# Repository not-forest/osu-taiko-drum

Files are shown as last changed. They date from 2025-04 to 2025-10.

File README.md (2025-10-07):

# 🥁 Osu! Taiko Drum Controller

A cross-platform, DIY **Taiko drum controller** designed for playing **[osu!taiko](https://osu.ppy.sh/home)** on PC. This controller functions as a fully configurable keypad that detects vibration-based hits and maps them to keypress events, serving as a general-purpose input device.

The project includes:

- Hardware schematics and PCB layout  
- Firmware written in Rust using RTIC framework
- GUI interface for configuring the drum from the host side (TODO!)
- Jupyter notebook for simulating piezoelectric sensor signals and modeling post-processing, which is then rewritten within the firmware in no_std environment
- A command-line utility for configuring the drum from the host side.  
- 3D-printable components for building the physical enclosure

---
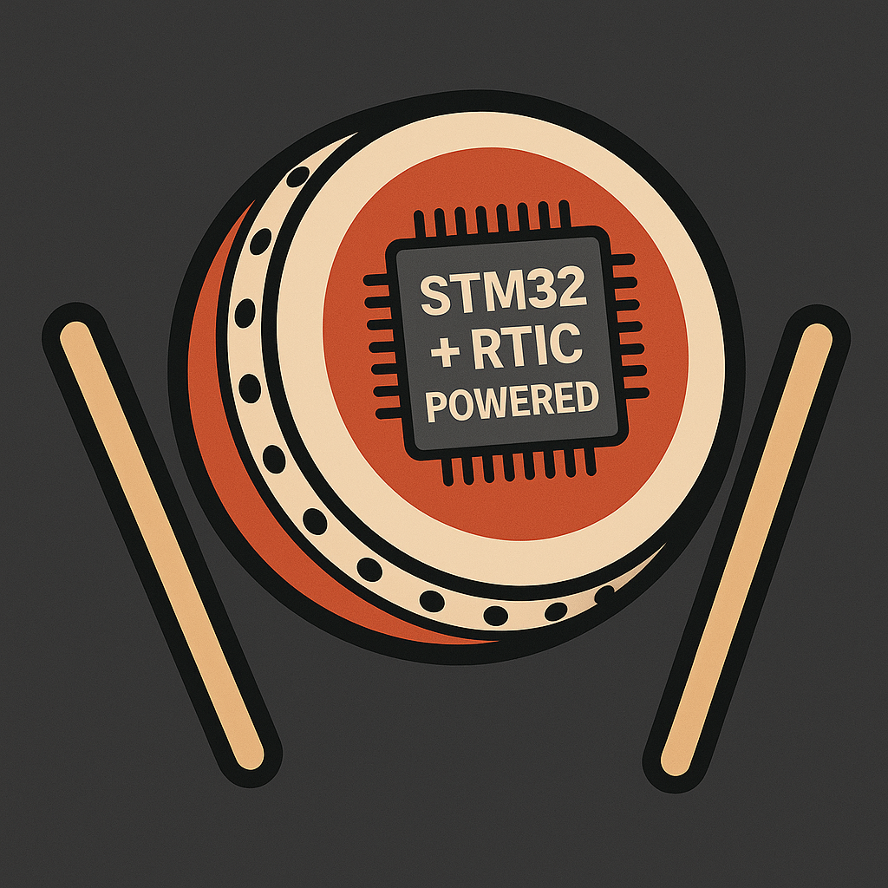
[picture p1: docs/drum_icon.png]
Taiko Drum Controller Icon

---

## Visual Overview

- **Assembled Physical Drum Controller**  
  Assembled Physical Representation

- **Electronic Schematic**  
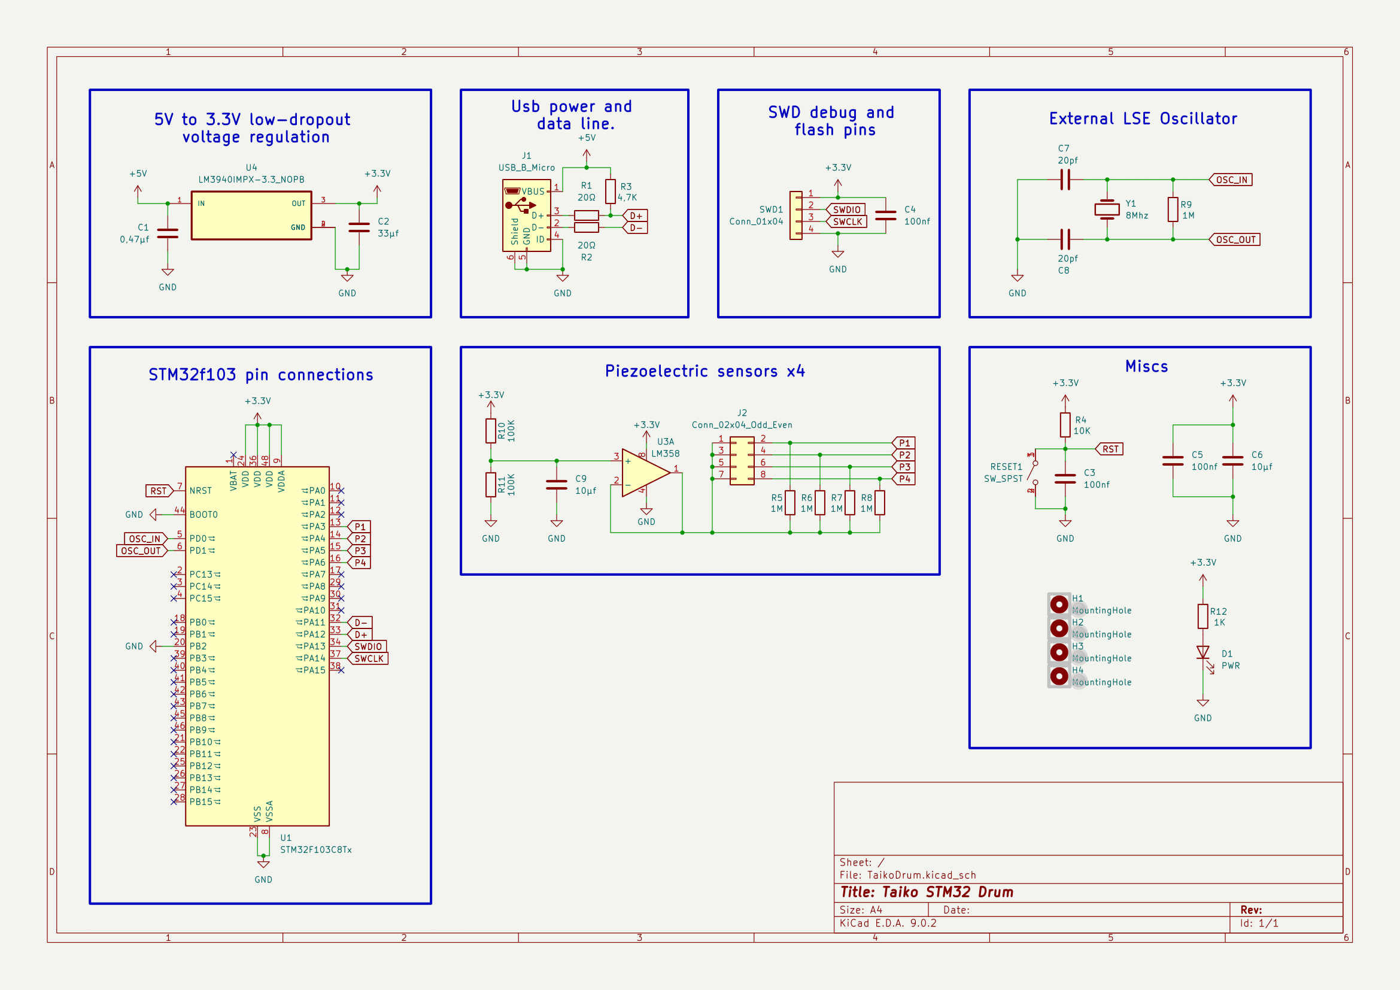
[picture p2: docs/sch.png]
Schematic
  

- **PCB Layout**  
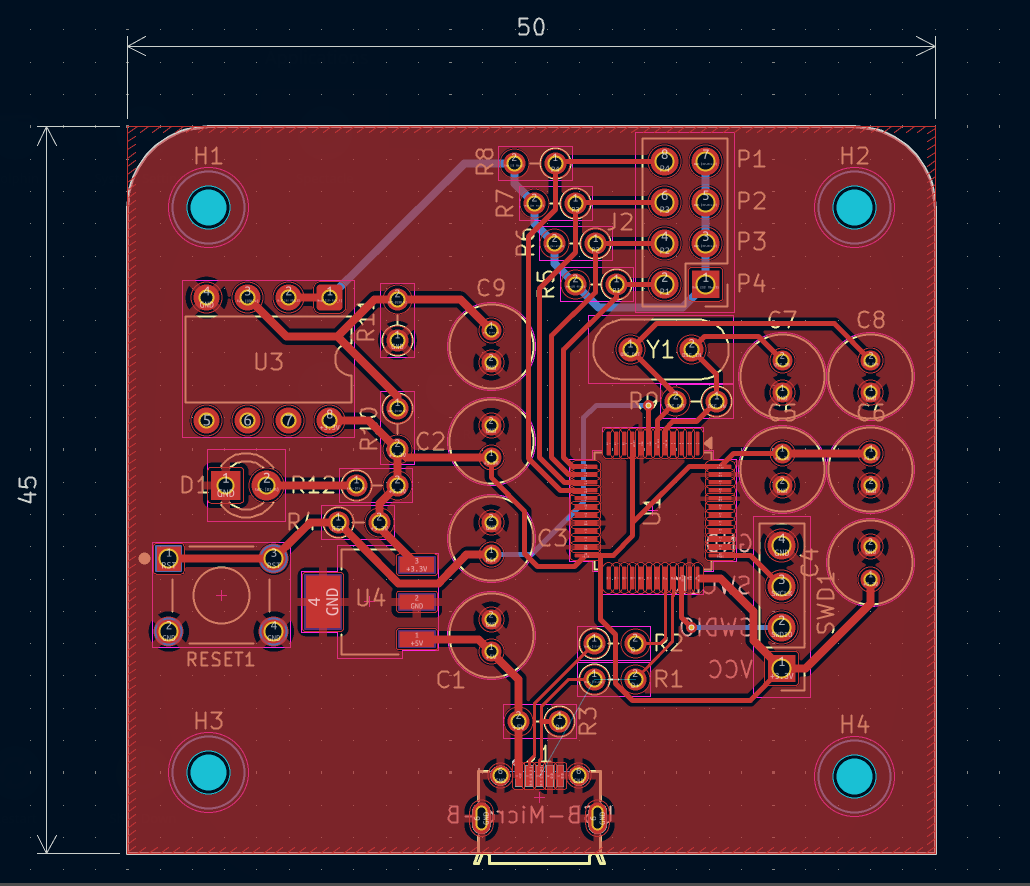
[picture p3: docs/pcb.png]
PCB Layout
  

---

### Project Overview

---

## Firmware

The firmware is written in Rust using the [RTIC framework](https://rtic.rs/), simulating a general-purpose HID device to ensure compatibility across all major operating systems. It simultaneously exposes a serial interface for configuration and control via utility software.

Each of the four piezoelectric sensors is sampled independently using dedicated ADC channels. The firmware captures both "Don" and "Kat" hits in pairs with minimal latency. Captured samples are fed into a queue and processed by a parser task that performs post-processing to detect real and spurious hits. Inner constants like `sensitivity` and `sharpness` are configurable from the utility software. Valid hits are mapped into keypresses and transmitted as USB HID reports.

All configuration data is stored in the last page of the flash memory and can be updated at runtime using the configuration utility.

---

## Hardware

The custom PCB is designed in KiCad and features core components typically found on “Blue Pill” development boards, including SWD debug headers and an onboard reset button. The controller is powered directly via USB, which also serves as the communication link for HID reports to the host system.

---

## Configuration Utility (TODO! swap to GUI utility)

A lightweight command-line utility written in Tcl is provided for runtime configuration. It allows to:

- Remap keypresses for each sensor. Can be changed to any proper keyboard key.
- Adjust hit detection `sensitivity` and `sharpness` to fine tune inner hit detection algorithm
- Send control commands, such as firmware reboot.
- Firmware update support (TODO!)

---

## 3D Printed Parts

All necessary 3D-printable components are located in the `3d/` directory. This includes:

- Raw Blender model files
- Cura-ready imported `.3mf` files

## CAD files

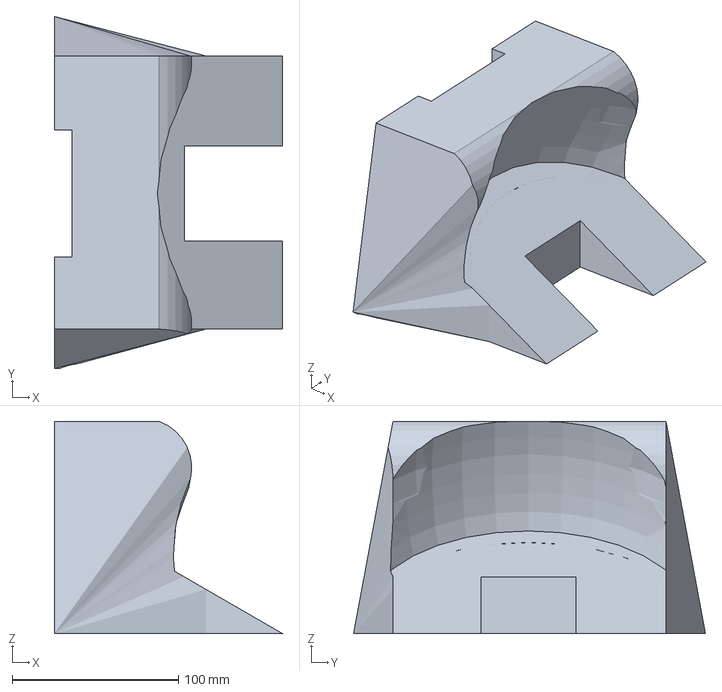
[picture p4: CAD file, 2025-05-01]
3d/SS_TaikoDrumStandFront.3mf
137.4 x 211.9 x 127.8 mm

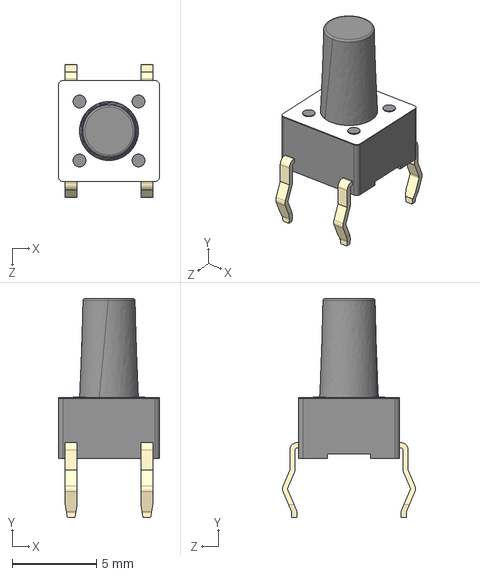
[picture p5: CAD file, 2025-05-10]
pcb/syms/FSM8JH/FSM8JH.step
5.99 x 13.0 x 7.90 mm

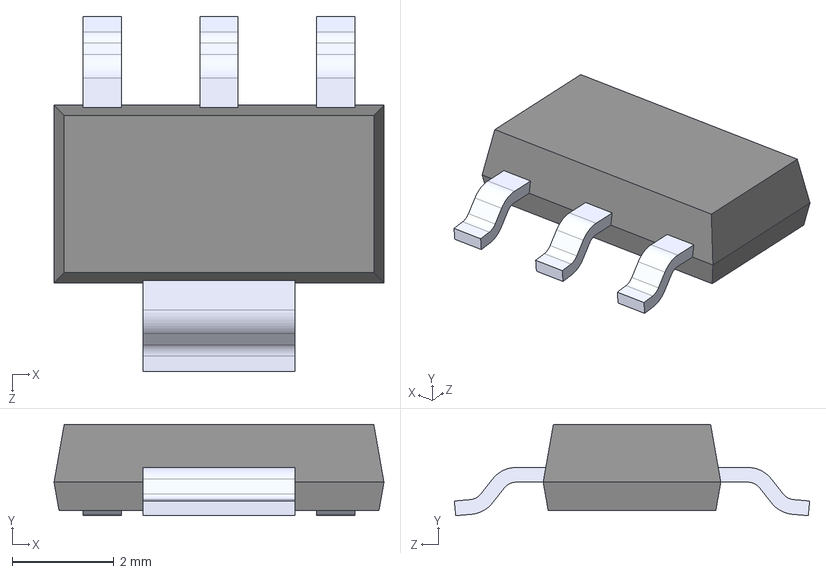
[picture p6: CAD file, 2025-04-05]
pcb/syms/LM3940IMPX-3.3_NOPB/LM3940IMPX-3.3_NOPB.step
6.50 x 1.80 x 7.00 mm

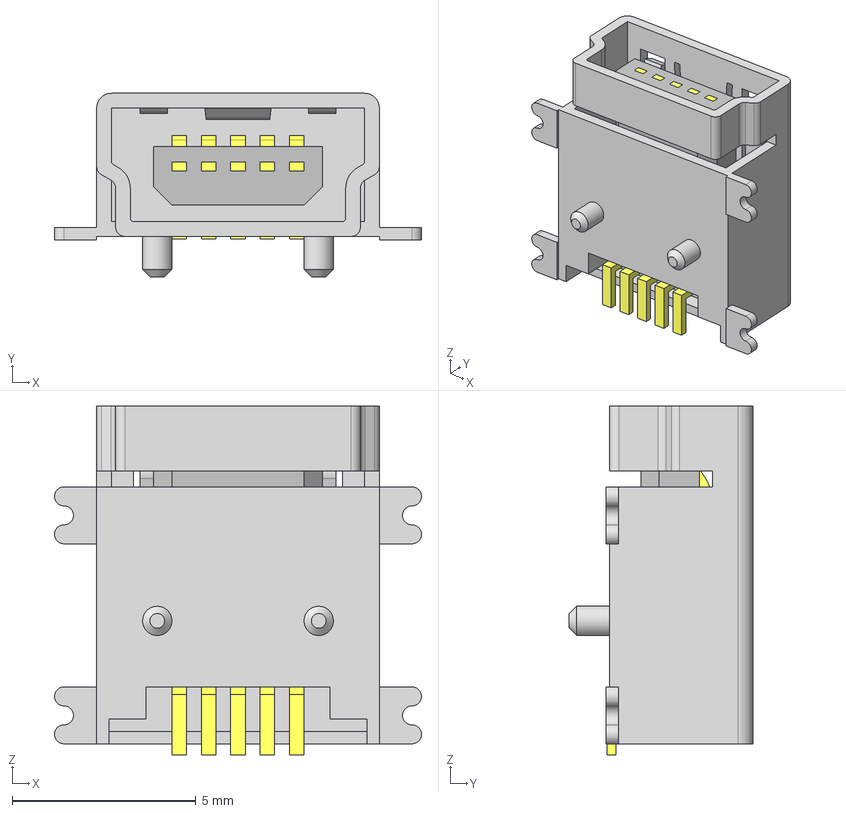
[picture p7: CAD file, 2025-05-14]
pcb/syms/MUSB-05-S-B-SM-A.stp
10.00 x 5.00 x 9.50 mm
MUSBB
MUSB-Body
MUSB-Pin

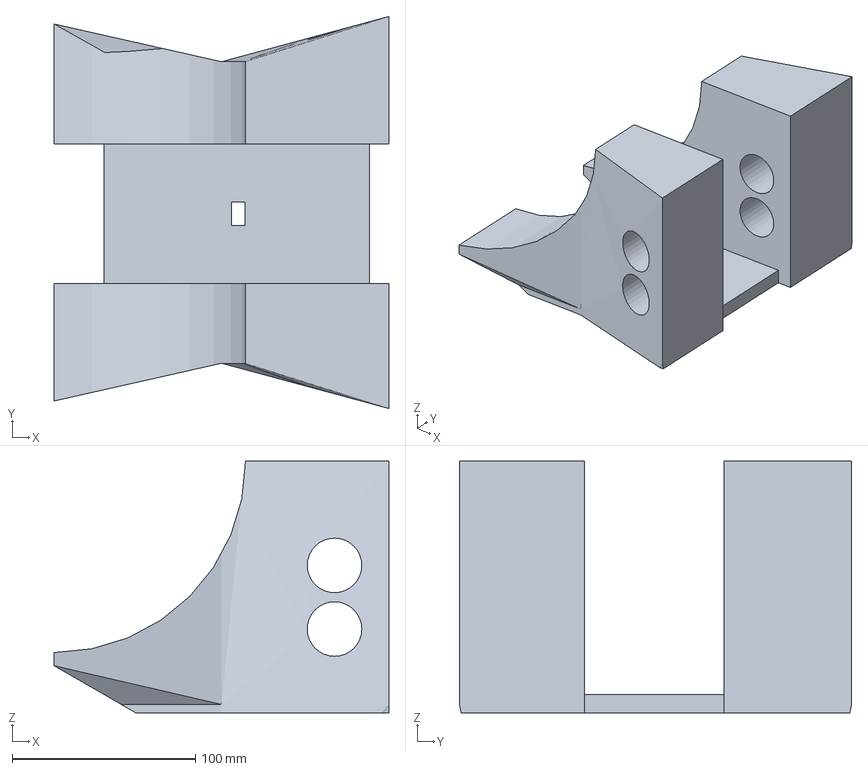
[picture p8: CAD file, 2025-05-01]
3d/SS_TaikoDrumStandBack.3mf
182.4 x 213.7 x 137.3 mm

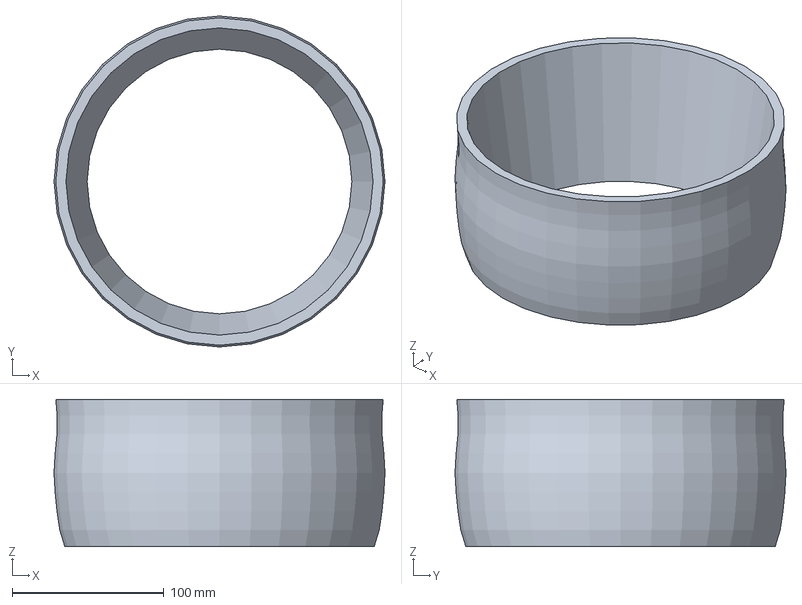
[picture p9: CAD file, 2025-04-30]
3d/SS_TaikoDrumBody.3mf
218.1 x 218.1 x 97.0 mm

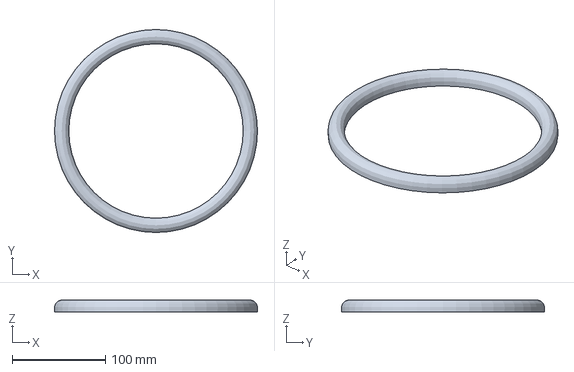
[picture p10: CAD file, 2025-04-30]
3d/SS_TaikoDrumKats.3mf
218.0 x 218.0 x 12.9 mm

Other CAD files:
3d/TaikoDrum.blend

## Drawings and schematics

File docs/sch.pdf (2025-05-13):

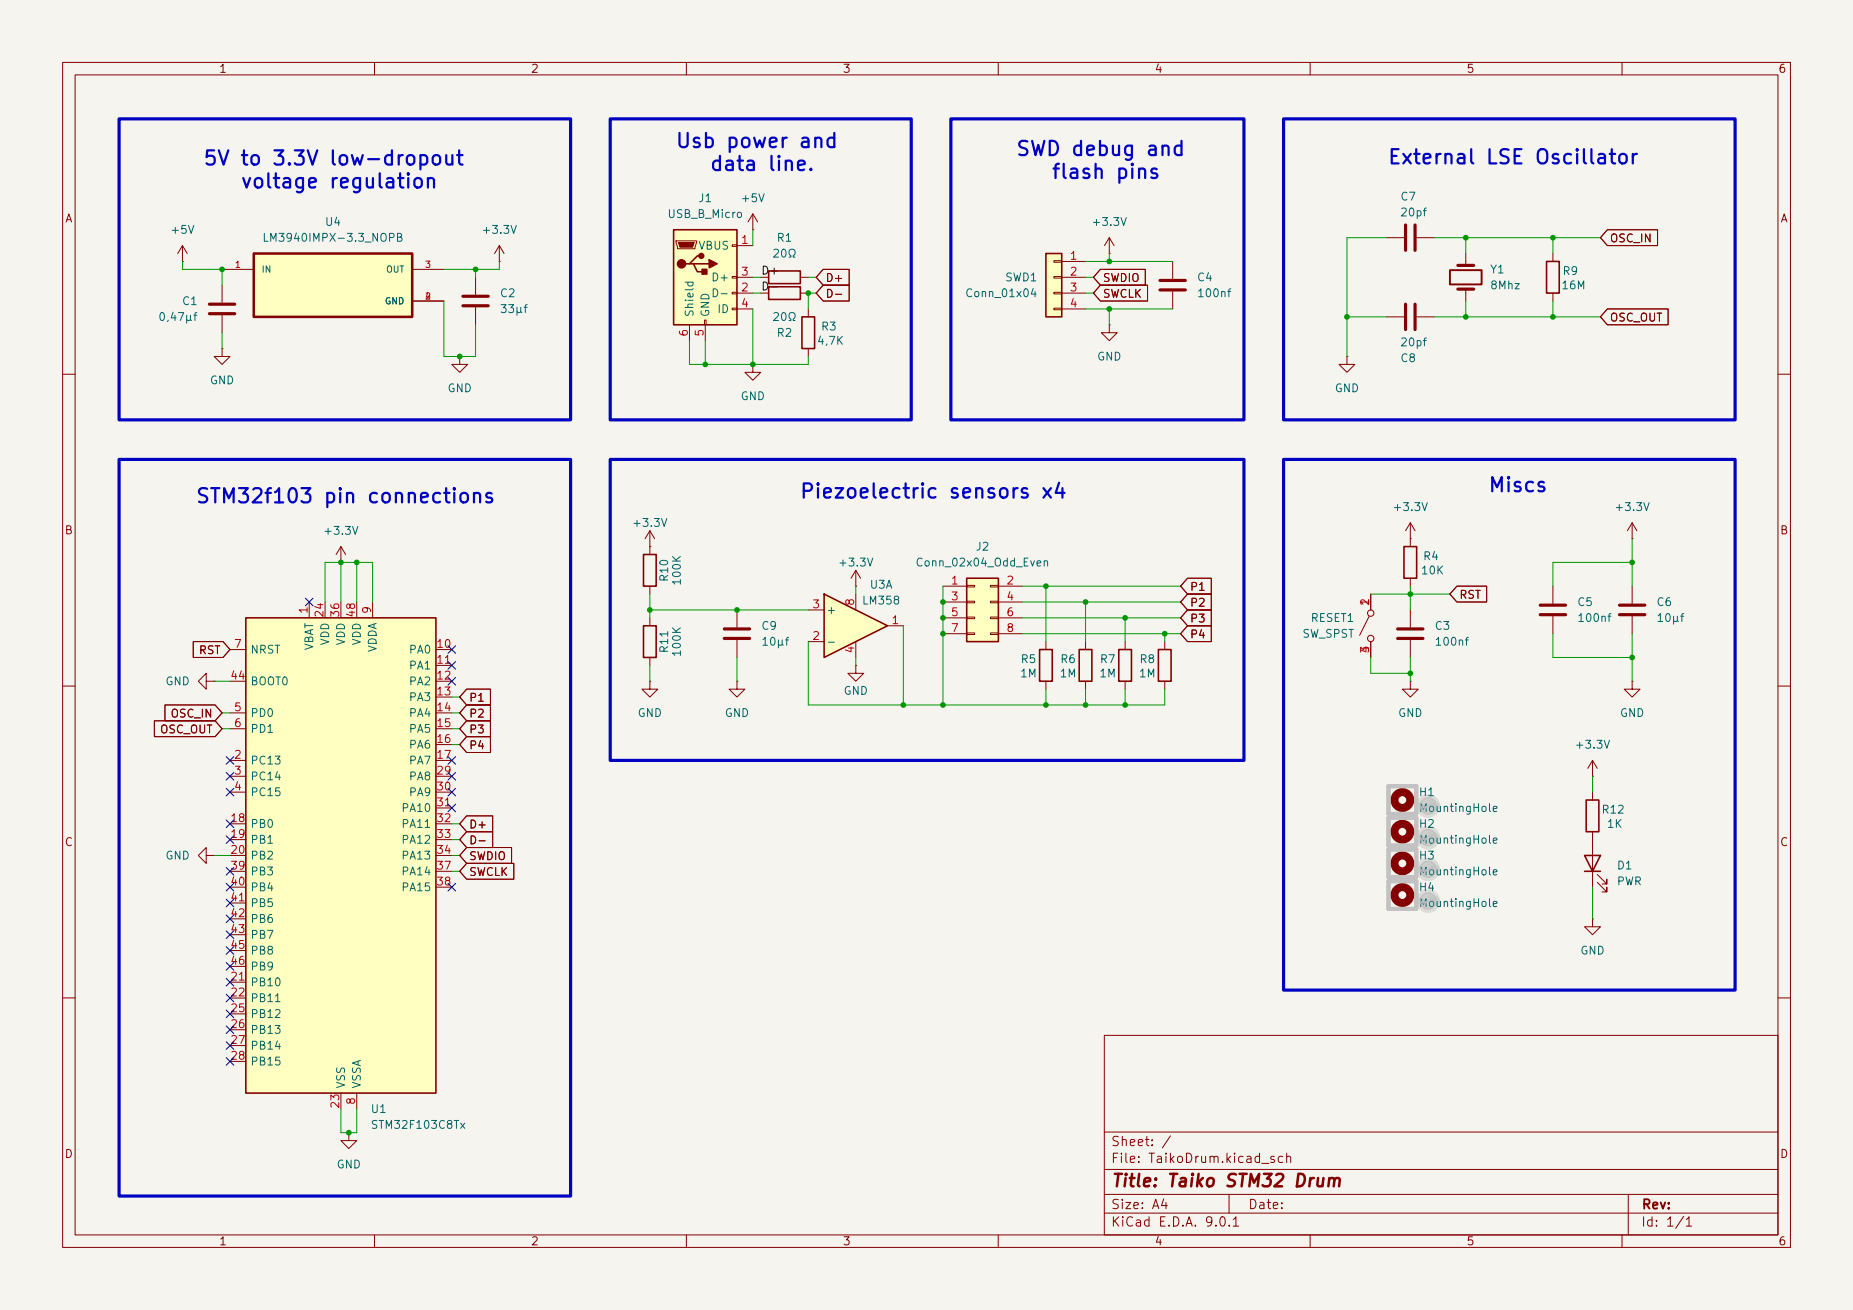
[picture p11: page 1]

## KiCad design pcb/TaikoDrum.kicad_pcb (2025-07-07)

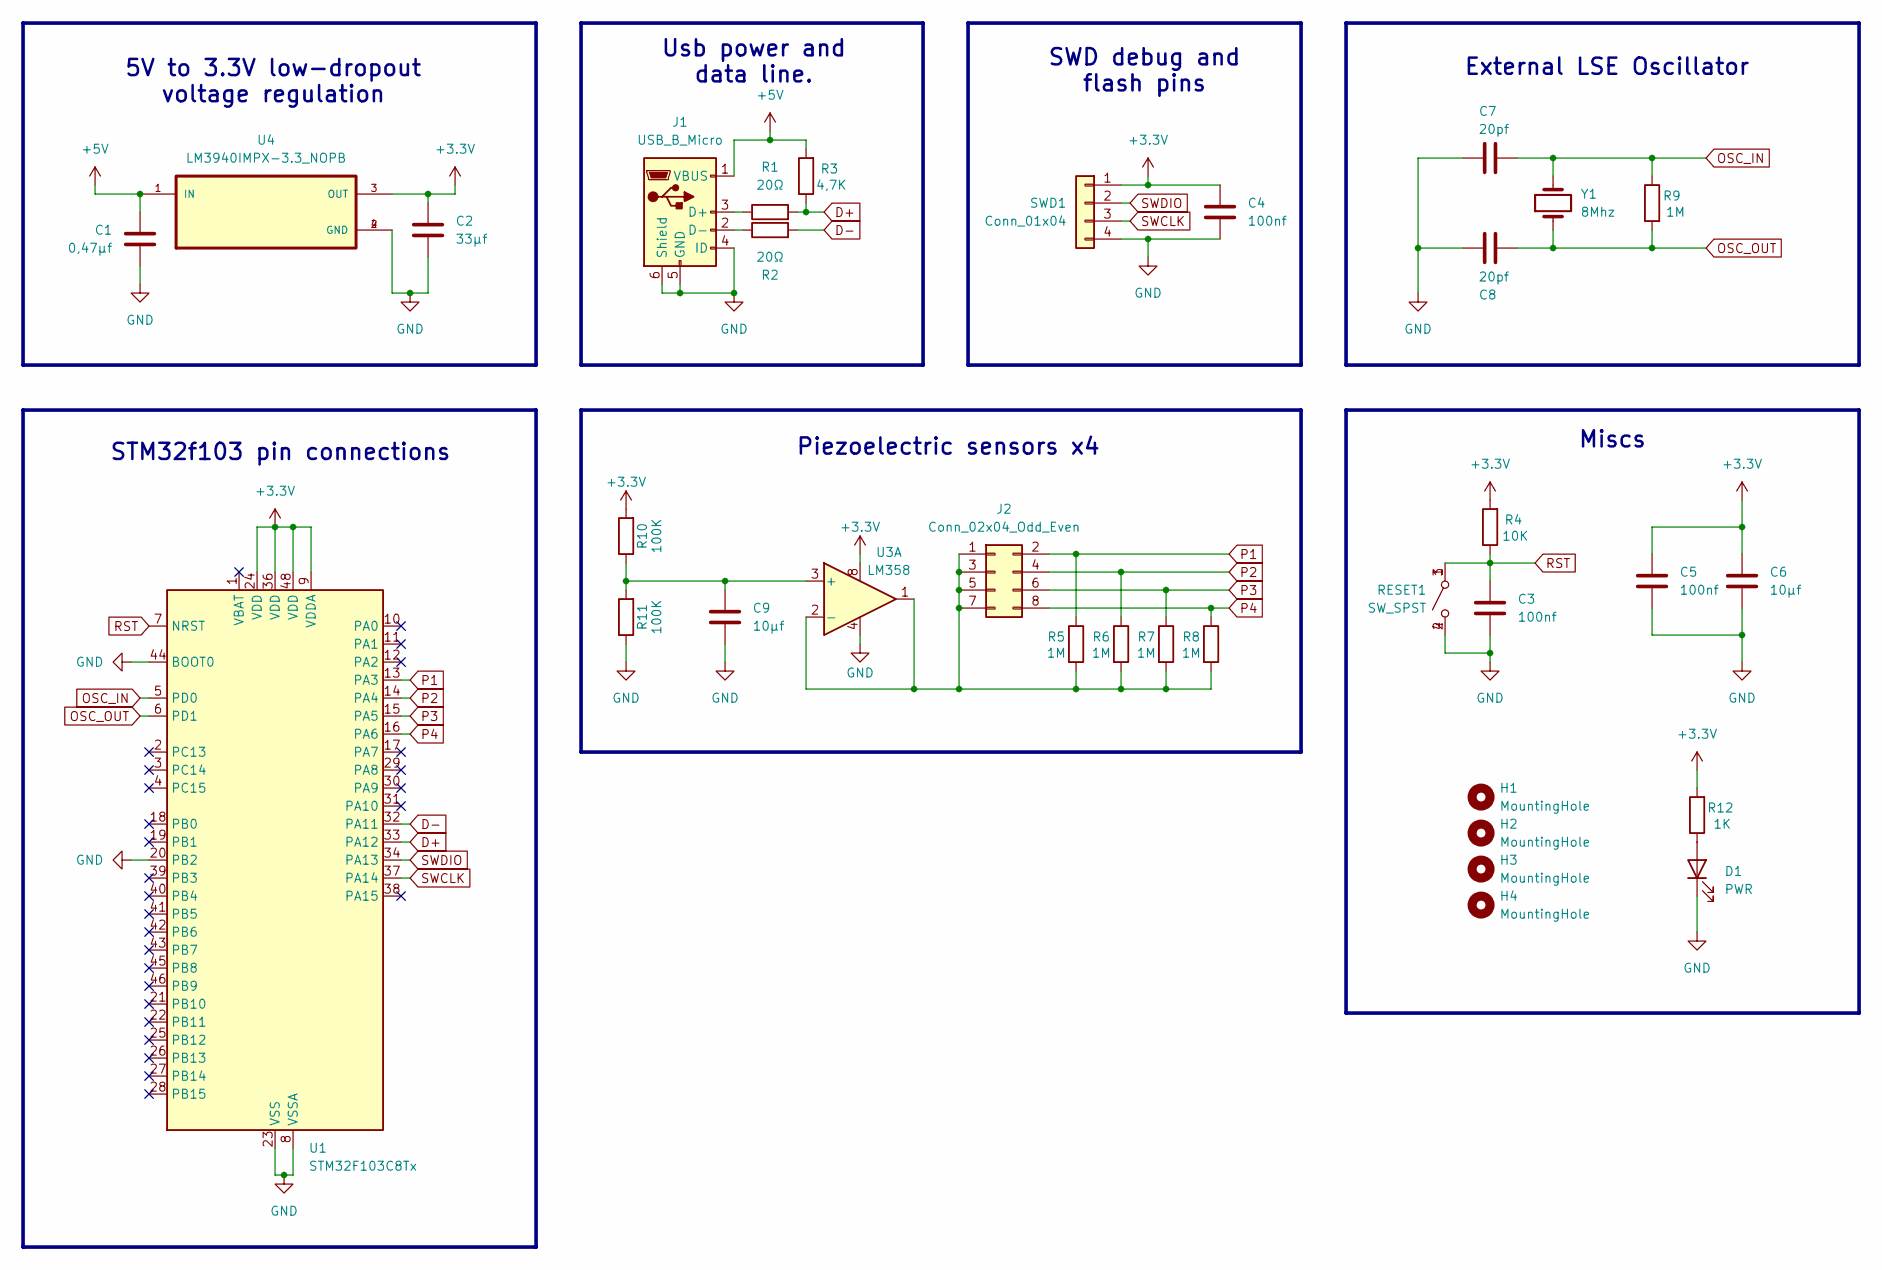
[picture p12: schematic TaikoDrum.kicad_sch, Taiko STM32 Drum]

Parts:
C1: 0,47µf; C_Radial_D5.0mm_H5.0mm_P2.00mm
C2: 33µf; C_Radial_D5.0mm_H5.0mm_P2.00mm
C3, C4, C5: 100nf; C_Radial_D5.0mm_H5.0mm_P2.00mm
C6, C9: 10µf; C_Radial_D5.0mm_H5.0mm_P2.00mm
C7, C8: 20pf; C_Radial_D5.0mm_H5.0mm_P2.00mm
D1: PWR; LED_D3.0mm
H1, H2, H3, H4: MountingHole; MountingHole_2.2mm_M2
J1: USB_B_Micro; MICRO-USB-SMD_5P-P0.65-H-F_C10418
J2: Conn_02x04_Odd_Even; PinHeader_2x04_P2.54mm_Vertical
R1, R2: 20Ω; R_Axial_DIN0204_L3.6mm_D1.6mm_P2.54mm_Vertical
R3: 4,7K; R_Axial_DIN0204_L3.6mm_D1.6mm_P2.54mm_Vertical
R4: 10K; R_Axial_DIN0204_L3.6mm_D1.6mm_P2.54mm_Vertical
R5, R6, R7, R8, R9: 1M; R_Axial_DIN0204_L3.6mm_D1.6mm_P2.54mm_Vertical
R10, R11: 100K; R_Axial_DIN0204_L3.6mm_D1.6mm_P2.54mm_Vertical
R12: 1K; R_Axial_DIN0204_L3.6mm_D1.6mm_P2.54mm_Vertical
RESET1: SW_SPST; SW_FSM8JH
SWD1: Conn_01x04; PinHeader_1x04_P2.54mm_Vertical
U1: STM32F103C8Tx; LQFP-48_7x7mm_P0.5mm
U3: LM358; DIP-8_W7.62mm
U4: LM3940IMPX-3.3_NOPB; SOT230P700X180-4N
Y1: 8Mhz; Crystal_HC52-U_Vertical

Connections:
+3.3V: C2.1, C4.1, C5.1, C6.1, R4.2, R10.2, R12.2, SWD1.1, U1.9 (VDDA), U1.24 (VDD), U1.36 (VDD), U1.48 (VDD), U3.8, U4.3 (OUT)
+5V: C1.1, J1.1 (VBUS), R3.2, U4.1 (IN)
D+: R1.2, R3.1, U1.33 (PA12)
D-: R2.2, U1.32 (PA11)
GND: C1.2, C2.2, C3.2, C4.2, C5.2, C6.2, C7.1, C8.1, C9.2, D1.1 (K), J1.4 (ID), J1.5 (GND), J1.6 (Shield), R11.1, RESET1.2 (B), RESET1.4 (B), SWD1.4, U1.8 (VSSA), U1.20 (PB2), U1.23 (VSS), U1.35 (VSS), U1.44 (BOOT0), U1.47 (VSS), U3.4, U4.2 (GND), U4.4 (GND)
unnamed: D1.2 (A), R12.1
unnamed: J1.3 (D+), R1.1
unnamed: J1.2 (D-), R2.1
unnamed: J2.1, J2.3, J2.5, J2.7, R5.2, R6.2, R7.2, R8.2, U3.1, U3.2 (-)
unnamed: C9.1, R10.1, R11.2, U3.3 (+)
OSC_IN: C7.2, R9.1, U1.5 (PD0), Y1.2
OSC_OUT: C8.2, R9.2, U1.6 (PD1), Y1.1
P1: J2.2, R5.1, U1.13 (PA3)
P2: J2.4, R6.1, U1.14 (PA4)
P3: J2.6, R7.1, U1.15 (PA5)
P4: J2.8, R8.1, U1.16 (PA6)
RST: C3.1, R4.1, RESET1.1 (A), RESET1.3 (A), U1.7 (NRST)
SWCLK: SWD1.3, U1.37 (PA14)
SWDIO: SWD1.2, U1.34 (PA13)

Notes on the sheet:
STM32f103 pin connections
Piezoelectric sensors x4
5V to 3.3V low-dropout voltage regulation
Usb power and data line.
Miscs
SWD debug and flash pins
External LSE Oscillator

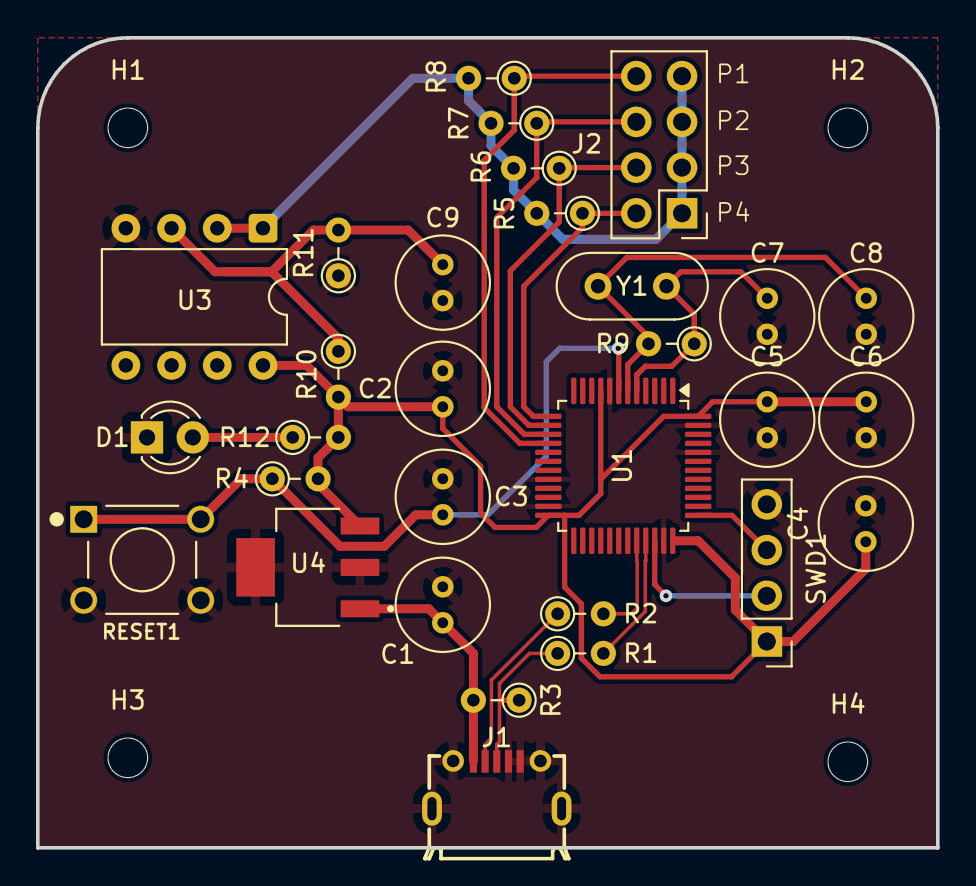
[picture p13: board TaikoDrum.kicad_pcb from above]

Board: 2 copper layers, 50.0 x 45.0 mm, 34 parts (0 on the bottom side), 19 nets.

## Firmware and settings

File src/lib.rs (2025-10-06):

//! Library space for Taiko Drum Firmware.
#![no_std]
#![no_main]
#![feature(slice_from_ptr_range)]

use stm32f1::stm32f103 as pac;

/// Contains configured logger for application.
mod logger;
/// Piezoelectric sensors driver.
mod piezo;
/// Parses samples to detect proper hits.
mod parser;
/// USB device handling.
mod usb;
/// HID class implementations for drum controller.
mod hid;
/// Firmware configuration (Non-volatile).
mod cfg;
/// Runtime programmer.
mod prog;
/// Cross-correlation signal processing.
mod cross_correlation;

#[rtic::app(
    device = stm32f1::stm32f103,
    dispatchers = [SDIO, RTC],
    peripherals = true,
)]
mod app {
    use usb_device::UsbError;
    use rtic_monotonics::systick::prelude::*;
    use rtic_sync::make_channel;

    use crate::hid::DrumHitStrokeHidReport;

    use super::cfg::DrumConfig;
    use super::piezo::{PiezoSample, PIEZO_SENSOR_QUEUE_CAPACITY, PiezoSensorHandler, Receiver};
    use super::usb::{UsbTaikoDrum, UsbAllocator, UsbBus};
    use super::parser::Parser as P;
    use super::prog::Programmer;

    /* Firmware clocks. */
    systick_monotonic!(Systick);

    #[shared]
    struct Shared {
        reset_pend: bool,
        /// Shared pins of GPIOA port.
        gpioa: super::pac::GPIOA,
        /// USB device wrapper is used across interrupt handlers and tasks to communicate withhost.
        usb_dev: UsbTaikoDrum<'static>,
    }
    
    #[local]
    struct Local {
        /// Local to ADC1_2 interrupt handler, which reads the state of current hits periodically.
        piezo_handler: PiezoSensorHandler,
        /// Sensor samples parser.
        parser: P,
    }

    /// Performs a software system reset.
    #[task(local = [timeout: u32 = 10], shared = [reset_pend])]
    async fn FirmwareReset(mut ctx: FirmwareReset::Context) {
        ctx.shared.reset_pend.lock(|pend| *pend = true);

        let timeout = *ctx.local.timeout;
        log::info!("A system reset was called. Restarting in {} seconds...", timeout);
        Systick::delay(timeout.secs()).await;
        rtic::export::SCB::sys_reset();
    }

    /// Initialization function for drum functionality.
    ///
    /// # Init
    ///
    /// During the initialization phase, application does the following:
    /// - Initializes the logger for debug and release builds;
    /// - Configures monotonic timers;
    /// - Prepares ADC1 & ADC2 for reading input from four piezoelectric sensors in injected
    /// simultaneous mode;
    /// - Prepares communication channel between [`app::SensorHandling`] and [`app::UsbHidSender`] tasks.
    #[init(
        local = [usb_alloc: Option<UsbAllocator> = None]
    )]
    fn Init(ctx: Init::Context) -> (Shared, Local) {
        let (core, mut dev, alloc) = (ctx.core, ctx.device, ctx.local.usb_alloc);
        let (s, r) = make_channel!(PiezoSample, PIEZO_SENSOR_QUEUE_CAPACITY);

        /* Logging initialization. */
        if let Err(log_set_err) = super::logger::init() {
            unimplemented!()
        }  
        log::info!("Booting taiko firmware version: [{}]", super::version::TAIKO_HID_FIRMWARE_VERSION);


        /* Setting SYSCLK source to PLL (72 MHz on this line.) */
        let (rcc, flash) = (&mut dev.RCC, &mut dev.FLASH);

        // Enabling internal high speed clock
        rcc.cr.modify(|_, w| w.hseon().set_bit());
        while rcc.cr.read().hserdy().bit_is_clear() {}

        rcc.cfgr.modify(|_, w|
            w   /* Multiplying HSE to reach a maximal value of 72 MHz */
             .pllsrc().set_bit()
             .pllxtpre().clear_bit()
             .pllmul().mul9()
        );

        // Enabling PLL.
        rcc.cr.modify(|_, w| w.pllon().set_bit());
        while rcc.cr.read().pllrdy().bit_is_clear() {}

        flash.acr.modify(|_, w| w.latency().ws2());

        // Architecture specific USB bus allocator.
        alloc.replace(UsbBus::new(super::usb::UsbControllerSTM32F103));

        // Sys clock switch.
        rcc.cfgr.modify(|_, w| w.sw().pll());
        while !rcc.cfgr.read().sws().is_pll() {}

        /* Monotonics. */
        log::debug!("Enabling Systick monotonic...");
        Systick::start(core.SYST, ARM_SYSTICK_HZ);
        log::info!("Internal clocks enabled");

        // Runtime firmware and configuration programmer.
        let programmer = Programmer::new(
            alloc,
            //DrumConfig::new(&mut dev.FLASH),
            DrumConfig::default(),
            dev.FLASH,
        );

        let usb_dev = UsbTaikoDrum::new(alloc, programmer, dev.USB, &mut dev.GPIOA, &mut dev.RCC);
        let piezo_handler = PiezoSensorHandler::new(
            (dev.ADC1, dev.ADC2), &mut dev.GPIOA, &mut dev.RCC, dev.TIM4, s.clone()
        );
        let cfg = &usb_dev.programmer.cfg;

        /* Tasks */ 
        Parser::spawn(r).expect("First parser initialization.");

        (
            Shared { usb_dev, gpioa: dev.GPIOA, reset_pend: false }, 
            Local { piezo_handler, parser: P::default() },
        )    
    }

    /// Parses upcoming samples to detect proper hits and ignore spurious ones.
    ///
    /// Obtained samples are being parsed to detect a proper drum hit and it's location. Based on
    /// the current hits, HID reports are being sent to the host machine, simulating a keyboard
    /// device that presses the corresponding keystrokes.
    #[task(local = [parser], shared = [usb_dev])]
    async fn Parser(mut ctx: Parser::Context, mut r: Receiver) {
        let parser = ctx.local.parser;
        log::info!("Parser task spawned. Waiting for samples.");

        /* Handling samples obtained from the piezoelectric sensor */
        while let Ok(sample) = r.recv().await {
            ctx.shared.usb_dev.lock(|dev| {
                parser.parse(&dev.programmer.cfg, sample).map(|report|
                    UsbHidSender::spawn(report).expect("Higher priority task spawn condition.")
                );
            });

            super::int_enable!(ADC1_2); // TODO! do not enable on each loop.
            Systick::delay(500.nanos()).await;
        }
    }

    /// Sends USB HID reports to the host machine.
    #[task(priority = 1, shared = [usb_dev])]
    async fn UsbHidSender(mut ctx: UsbHidSender::Context, report: DrumHitStrokeHidReport) {
        ctx.shared.usb_dev.lock(|dev| {
           
            dev.poll();
            match dev.hid_keyboard.push_input(&report) {
                Ok(report_length) => {
                    log::debug!("Bytes send: {}", report_length);
                },
                Err(usb_err) => match usb_err {
                    // Checking if device is properly initialized at that point.
                    UsbError::WouldBlock => dev.init_poll(),
                    UsbError::Unsupported => (),
                    _ => panic!("{:?}", usb_err),
                }
            }
        });
    }

    /// Piezoelectric sensor handling hardware task.
    ///
    /// # Binds
    ///
    /// This handler function is binded to ADC1_2 interrupt vector. 
    ///
    /// The underlying sensor handling structure is queuing next injected sample from the ADC pin
    /// to the [`super::app::UsbHidSender`] task.
    #[task(binds = ADC1_2, priority = 2, local = [piezo_handler])]
    fn SensorHandling(ctx: SensorHandling::Context) {
        ctx.local.piezo_handler.send();
    }

    /// USB TX Polling.
    #[task(binds = USB_HP_CAN_TX, priority = 2, shared = [usb_dev])]
    fn UsbPollTx(mut ctx: UsbPollTx::Context) {
        log::debug!("USB_EVENT_Tx");
        ctx.shared.usb_dev.lock(|dev| {
            crate::app::__usb_poll(dev);
        });
    }

    /// USB RX Polling.
    #[task(binds = USB_LP_CAN_RX0, priority = 2, shared = [usb_dev])]
    fn UsbPollRx(mut ctx: UsbPollRx::Context) {
        log::debug!("USB_EVENT_Rx");
        ctx.shared.usb_dev.lock(|dev| {
            dev.init_poll();   /* Low priority interrupts include enumeration requests and error handling. */
            crate::app::__usb_poll(dev);
        });
    }

    fn __usb_poll(dev: &mut UsbTaikoDrum) {
        dev.poll();
        dev.programmer.program();
    }

    // Panic handler.
    //
    // Performs a full system reset after a several second timeout.
    // TODO! Perform a better panic restart procedure.
    panic_custom::define_panic!(|info| {
        log::error!("System panic occured: {}", info);
    });

    const ARM_SYSTICK_HZ: u32 = 72_000_000;
}

#[macro_export]
macro_rules! int_enable {
    ($name:ident) => {
        unsafe {
        cortex_m::peripheral::NVIC::unmask(super::pac::Interrupt::$name); 
        }
    };
}

#[macro_export]
macro_rules! int_disable {
    ($name:ident) => {
        cortex_m::peripheral::NVIC::mask(super::pac::Interrupt::$name); 
    };
}

/// Module containing all information about current firmware version.
mod version {
    /// Current firmware version triple is aligned with crate version.
    pub(crate) const TAIKO_HID_FIRMWARE_VERSION: &'static str = env!("CARGO_PKG_VERSION");
    /// Current firmware version triple in BCD format for USB HID. 
    pub(crate) const TAIKO_HID_FIRMWARE_VERSION_BCD: u16 = __version_to_bcd(TAIKO_HID_FIRMWARE_VERSION);

    /// Converts current version number to BCD at compile time.
    const fn __version_to_bcd(version: &str) -> u16 {
        let mut major = 0;
        let mut minor = 0;
        let mut idx = 0;

        // Major
        while idx < version.len() {
            let byte = version.as_bytes()[idx];
            if byte == b'.' || byte == b'\0' {
                break;
            }
            major = major * 10 + (byte - b'0') as u16;
            idx += 1;
        }

        idx += 1;

        // Minor
        while idx < version.len() {
            let byte = version.as_bytes()[idx];
            if byte == b'.' || byte == b'\0' {
                break;
            }
            minor = minor * 10 + (byte - b'0') as u16;
            idx += 1;
        }

        (major << 8) | minor
    }
}

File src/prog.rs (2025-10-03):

//! Runtime programmer for configuration and firmware.

use usbd_hid::UsbError;
use usbd_serial::embedded_io::{Read, ReadReady, Write};
use usbd_serial::SerialPort;

use super::pac::FLASH;
use super::cfg::DrumConfig;
use super::usb::{UsbBus, UsbAllocator};

const COMM_IF_NAME: &'static str = "Taiko Drum CDC Control";
const DATA_IF_NAME: &'static str = "Taiko Drum CDC Data";
const BUFF_LEN: usize = 16;
const ACK: u8 = 0x06;

/// Local serializer implementation used to communicate with taiko drum utility.
trait ProgrammerSerializer: Sized {
    type Error: Sized;
    /// Serializes a structure in a proper format for utility read.
    fn serialize(&self, buff: &mut [u8; BUFF_LEN]);
    /// Deserializes upcoming stream of bytes from the utility into a structure of corresponding type.
    fn deserialize(&self, buff: &[u8]) -> Result<Self, Self::Error>;
}

#[repr(u8)]
enum Command {
    /// Unknown state.
    Unknown = 0x00,
    /// Read current configuration.
    Read    = 0x01,
    /// Write new configuration.
    Write   = 0x02,

    /// Reset the firmware.
    Reset   = 0xff,
}

impl TryFrom<u8> for Command {
    type Error = u8;
    fn try_from(value: u8) -> Result<Self, Self::Error> {
        use Command::*;
        Ok(match value {
            0x00 => Unknown,
            0x01 => Read,
            0x02 => Write,

            0xff => Reset,
            _ => return Err(value)
        })
    }
}

/// Runtime Programmer.
///
/// Utilizes the serial port in order to perform basic tasks obtained from the host machine via
/// application specific utility. Below is the list of currently available features of this
/// programmer:
/// - Configuration Management (reading the configuration from flash and saving new one.);
/// - Reset the firmware;
pub(crate) struct Programmer<'a> {
    /// Serial port interface for straight communication between host and firmware.
    pub(crate) serial: SerialPort<'a, UsbBus>,
    /// Holds current drum configuration.
    pub(crate) cfg: DrumConfig,
    /// Flash is only controller by [`UsbConfigManager`] task to save new configurations on runtime.
    pub(crate) flash: super::pac::FLASH,
}

impl<'a> Programmer<'a> {
    /// Initializes new instance of [`Programmer`]
    pub(crate) fn new(alloc: &'a Option<UsbAllocator>, cfg: DrumConfig, flash: FLASH) -> Self {
        let serial = SerialPort::new_with_interface_names(
            alloc.as_ref().expect("Won't panic if this function is only called once."),
            Some(COMM_IF_NAME),
            Some(DATA_IF_NAME),
        );
        Self { serial, cfg, flash }
    }
}

impl Programmer<'_> {
    pub(crate) fn info(&self) {
        let lc = self.serial.line_coding();
        log::info!("Runtime programmer configured with: {:?}, {:?}, {}", 
            lc.data_rate(), lc.data_bits(), lc.stop_bits() as u8
        )
    }

    /// Command parsing and execution function.
    pub(crate) fn program(&mut self) {
        let mut buff = [0u8; BUFF_LEN];

        rtic::export::interrupt::free(|_| {
            // Perform a non-blocking read.
            if let Ok(true) = self.serial.read_ready() {
                match self.serial.read(&mut buff) {
                    Ok(rsize) => if rsize > 0 {
                        // Performing only properly parsed CMDs.
                        match buff[0].try_into() {
                            Ok(cmd) => match cmd {
                                Command::Reset => {
                                    self.ack();
                                    super::app::FirmwareReset::spawn().expect("Reset function cannot be called more than once.");
                                },
                                Command::Read => {
                                    self.ack();
                                    self.cfg.serialize(&mut buff);
                                    // Sending current configuration back.
                                    match self.serial.write(&buff) {
                                        Ok(wsize) => log::info!("Current configuration was send [{}] bytes", wsize),
                                        Err(err) => todo!(),
                                    }
                                    self.serial.flush().ok();
                                }
                                Command::Write => {
                                    self.ack();

                                    // Mutates current configuration based on obtained data.
                                    match self.cfg.deserialize(&buff) {
                                        Ok(new_cfg) => {
                                            self.cfg = new_cfg;
                                            self.cfg.save(&mut self.flash);
                                            log::info!("Writing new configuration:\n{:#?}", new_cfg);
                                        },
                                        Err(byte) => if byte != 0 { 
                                            log::error!("Unexpected byte value obtained: {}", byte) 
                                        },
                                    }
                                }
                                _ => (),
                            }
                            Err(err) => log::warn!("Unknown command byte received: {:#x}, ignoring...", err),
                        }
                    },
                    Err(usb_err) => match usb_err {
                        UsbError::WouldBlock | UsbError::Unsupported => (),
                        _ => panic!("{:?}", usb_err),
                    }
                }
            }
        });
    }

    /// Sends an acknowledge signal with a small delay.
    fn ack(&mut self) {
        if let Err(err) = self.serial.write(&[ACK]) {
            todo!()
        }
        cortex_m::asm::delay(720);
    }
}

/* Constant bytes are completely equal to those defined within the taiko drum control utility. */
const LEFTKAT: u8 = 0x10;
const LEFTDON: u8 = 0x11;
const RIGHTDON: u8 = 0x12;
const RIGHTKAT: u8 = 0x13; 
const SENS: u8 = 0x20;
const SHARP: u8 = 0x21;
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

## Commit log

2025-04-05 First PCB skeleton with USB-STM32f103 connection and voltage regulation.
    [LM3940IMPX-3.3_NOPB.STEP, LM3940IMPX-3.3_NOPB.step, TaikoDrum.kicad_sch]
2025-04-06 Creates RTIC project skeleton for STM32F103 microcontroller.
    [stlink.cfg]
2025-04-06 Switched to RTICv2.
2025-04-07 Completed the first theoretical schematic prototype.
    [TaikoDrum.kicad_sch]
2025-04-09 Added module for handling piezoelectric sensor data from selected analog pins simultaneously via two ADC's working in master-slave mode with injected channels used to sample center and edge drum hits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
2025-04-09 Added external oscillator and decouplers for the Taiko Drum circuit.
    [TaikoDrum.kicad_sch]
2025-04-10 Added 16M resistor for external LSE oscillator according to the STM32F103 errata recomendations.
    [TaikoDrum.kicad_sch]
2025-04-12 Added device information strings. Serial number is being generated based from md5 hash based on the current firmware version.
2025-04-16 Detecting a proper USB device on the host machine. Fixed the USB peripheral to obtain a proper 48 MHz clock signal and PCLK1 to be larger than 8MHz. Additional initialization polling is done to allow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
    [lib.rs]
2025-04-17 Added better initialization polling handling during device's start. Separated the gpio disconection part to allow future reconnection from other parts of the firmware.
2025-04-17 Now only perform init polling check on low-priority interrupt. Better error handling for HID report test.
    [lib.rs]
2025-04-18 Interrupt free initialization allows for faster USB enumeration.
2025-04-19 Added configuration TCL script to configure the device via USB serial interface.
2025-04-30 Added raw 3D models, Cura sliced models and G-Code for Taiko Drum
    [SS_TaikoDrumBody.3mf, SS_TaikoDrumKats.3mf, SS_TaikoDrumStandBack.3mf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]
2025-05-01 Stand model update.
    [SS_TaikoDrumStandBack.3mf, SS_TaikoDrumStandFront.3mf, TaikoDrum.blend]
2025-05-01 Used an additional voltage divider to not loose any energy from the piezo signal.
    [TaikoDrum.kicad_sch]
2025-05-04 Added first version of parser algorith with dynamic energy-based thresholding. Only works on a singular channel for now. (Very unstable).
    [lib.rs, piezo.rs]
2025-05-06 Swapped static parser key mappings to those used in current configuration.
    [lib.rs, prog.rs]
2025-05-06 Swapped to individual adaptive threshold for each piezo channel. Improved HID report sending and reduced latency.
    [lib.rs]
2025-05-07 Updated PCB schematic.
    [TaikoDrum.kicad_sch]
2025-05-08 Fixed programmer not being able to obtain CPU cycles due to rapid interrupts. Implemented fully working reading procedure. TODO! fix writing procedure to obtain byte-by-byte data.
    [lib.rs, prog.rs]
2025-05-09 Better LM358 based op-amp buffering for piezo voltage dividers.
    [TaikoDrum.kicad_sch]
2025-05-10 Improved the schematic design with shared buffer for all four piezos and extra decoupling. Created first PCB design with all required components for THT soldering (except for STM32).
    [FSM8JH--3DModel-STEP-56544.STEP, FSM8JH.step, TaikoDrum.kicad_pcb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]
2025-05-13 Added docs. Modified README.
    [TaikoDrum.kicad_pcb]
2025-05-14 Fixed wrong USB wiring. Removed unecessary marks.
    [MUSB-05-S-B-SM-A.stp, TaikoDrum.kicad_pcb, TaikoDrum.kicad_sch]
2025-05-14 Better diff line routing. Additional dev text.
    [TaikoDrum.kicad_pcb]
2025-05-20 Fixed sharpness configuration programming method.
    [prog.rs]
2025-05-30 Fixed microcontroller GNDing.
    [TaikoDrum.kicad_pcb]
2025-06-22 Fixed all paths within the controller design. Swapped the micro USB footprint with JLCPCB compatible for auto assembly. Fixed clearance.
    [TaikoDrum.kicad_pcb, TaikoDrum.kicad_sch]
2025-07-06 Silkscreen names for SWD pads are now named correctly.
    [TaikoDrum.kicad_pcb]
2025-07-07 Fixed the D+ line. the PCB schematic and layout is now 100% fully workable design. Fixed the button connection to be compatible with most generic tactile switches.
    [TaikoDrum.kicad_pcb, TaikoDrum.kicad_sch]
2025-07-11 Updated docs with newest schematics/PCB
2025-10-03 Slight changes in parser implementation. Do not use energies anymore because they provide completely chaotic results during fast hits and loose delay information just like FFT. Using deviation as a f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
    [prog.rs]
2025-10-06 Fixing the sample window structure. Adjusted window length to fit flash's size properly without affecting USBD definitions in .bss sector. Made cross-correlation filtering little bit better. May requ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
    [lib.rs]

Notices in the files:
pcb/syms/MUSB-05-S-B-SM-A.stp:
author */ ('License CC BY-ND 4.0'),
